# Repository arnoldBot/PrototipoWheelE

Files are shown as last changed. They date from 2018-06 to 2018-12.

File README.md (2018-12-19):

# PrototipoWheelE

Proyecto desarrollado por un grupo en la Universidad. El proyecto es un primer prototipo,
posteriormente se espera modificar el robot de 0 para hacer una nueva versión.

Es un diseño completo en el cuál se incluye:
  - Control Brazo Robótico
  - Servidor Web en Apache y página web
  - Control movimiento Rover
  - Diseño CAD del robot
  - Misceláneas varias

Especial mención a la parte del Servidor Web, en concreto a la implementación de la página web en Apache, ya que es totalmente funcional y extensible.

Se espera mejorar éste proyecto emplendo ROS y OpenCV.

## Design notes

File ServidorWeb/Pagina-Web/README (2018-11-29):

INSTRUCCIONES DE INSTALACIÓN Y PREPARACIÓN DE UN SERVIDOR WEB EMPLEANDO APACHE Y RASPBERRY PI

REQUISITOS PREVIOS
1-  Descargar de la página oficial de Raspberry Pi la distro de Jessie:
    https://www.raspberrypi.org/downloads/raspbian/

2-  Descargar la herramienta Rufus, para grabar imagenes iso en una SD:
    https://rufus.akeo.ie/?locale=es_ES
    (Posibilidad de emplear el comando "dd" en la terminal de Linux)

3-  Es NECESARIO emplear una tarjeta SD mayor a 8gb. (Formateada)
---------------------------------------------------------------------------------------------
INSTALACIÓN DE APACHE
4-  Grabamos la imagen de Jessie en nuestra SD y, posteriormente, introducimos la SD en la 
    Raspberry Pi y conectamos la alimentacion, una salida HDMI, un teclado y un ratón.
5-  Una vez se haya iniciado la Raspberry, abrimos la terminal y escribimos:
    "$ sudo raspi-config". Nos saltará otra interfaz, buscamos "Interfacing Options" y lo
    abrimos, ahí seleccionamos Camera, SSH y Serial.
    Vamos a atrás y le damos a "Advance Options" y seleccionamos "Expand Filesystem".
    Le damos a finish y la Raspberry Pi se reiniciará automaticamente.
6-  Posteriormente, de vuelta en el escritorio de Jessie, abrimos la terminal y escribimos:
    "$ sudo apt-get update".
7-  A continuación tecleamos: "$ sudo apt-get install apache2"
8-  Una vez instalado Apache en la Raspberry Pi, conviene comprobar si el servidor funciona.
    Para ello, necesitaremos un ordenador o dispositivo móvil, y conocer la ip de la Raspberry.
    Para comprobarlo, abrimos el navegador e introducimos en el browser la ip de la Raspberry
    y debería aparecer la página de Apache.

CONFIGURACIÓN DE APACHE
9-  Para configurarlo, en primer lugar debemos activar el cgi mediante: "$ sudo a2enmod cgi".
    Posteriormente, debemos configurar el directorio html, el cúal se encuentra en 
    /var/www/html/ para que pueda ejecutar scripts CGI. Para ello, debemos añadir las
    siguientes lineas de código al fichero apache2.config. (Éste fichero se encontrará dentro
    de /etc (creo), para abrirlo bastaría con: "$ sudo nano apache2.config".):

		~~~~~~~~~~~~~~~~~~~~~~~~~~~~~~~~~~~~~~~~~~~~~~~~~
		~	ScriptAlias  /cgi-bin/ /var/www/html/   ~
		~                                               ~
		~		<Directory /var/www/html/>      ~
		~    	    Options +ExecCGI                    ~
		~    	    AddHandler cgi-script .cgi .py      ~
		~		</Directory>                    ~
		~~~~~~~~~~~~~~~~~~~~~~~~~~~~~~~~~~~~~~~~~~~~~~~~~

   Una vez añadido, guardamos el archivo y reiniciamos la raspberry mediante: "$ sudo shutdown
   now".

ASIGNACIÓN DE PERMISOS
9-  Por defecto, el usuario apache estará dentro del grupo www-data, para tener los mismos
    permisos que apache, debemos añadir nuestro usuario, pi, a dicho grupo, es decir, www-data.
    Para ello, emplearemos el comando: "$ sudo adduser pi www-data".
10- A continuación, debemos hacer que el dueño del directorio /var/www/ pertenezca a al grupo
    www-data. Para ello, emplearemos: "$ sudo chown -R www-data:www-data /var/www".
    Ahora que hemos cambiado de dueño vamos a darle todo tipo de permimos al nuevo, para ello
    emplearemos el comando: "$sudo chmod -R g+rwX /var/www".
11- Por otro lado, debemos darle permisos de apertura, lectura y escritura a los archivos 
    (o carpetas) cgi que queremos que la página ejecute. Para ello emplearemos el comando:
    "$ sudo chmod 777 <nombrefichero.loquesea> (Hay que darselo a todos los archivos, es
    importante no olvidarlo).
12- Además, también es necesario darle permisos al grupo www-data para poder abrir los
    puertos. 
    Para ello, emplearemos: "$ sudo usermod -a -G dialout www-data".

TRANSFERENCIA DE DATOS CREADOS PARA LA WEB (CSS,HMTL,JS,ETC.)
13-  De vuelta a nuestro ordenador,debemos transferimos los datos creados en para la página web
    a la Raspberry, para ello emplearemos la herramienta "Filezilla". Para instalarla, abrimos
    la terminal y tecleamos: "$ sudo apt-get install filezilla".
14- Una vez dentro del programa, rellenamos los siguientes campos:
		host: <ip raspberry>
		username: <pi>
		password: <contraseña de la rasp> (Por defecto, pass=raspberry)
		port: <22>
15- Una vez nos hayas conectado a la Raspberry Pi mediante ssh empleando Filezilla, copiamos el
    contenido de la carpeta <Servidor_web> dentro de la ruta "/var/www/html/".
----------------------------------------------------------------------------------------
      DE ÉSTE MODO QUEDARÁ TOTALMENTE OPERATIVA LA RASPBERRY PI CON EL SERVIDOR PARA TRABAJAR
      CON ELLA.

----------------------------------------------------------------------------------------
ANEXO: ANTE POSIBLES PROBLEMAS CON PYTHON

Asegurar que el directorio de python es correcta en la primera lina de los scripts:
	para ello hacemos miramos si estan la libreria pySerial instalada correctamnte con:
	
		~$pip list 		// Si es python
			ó 
		~$pip3 list		// Si es python3
				
	si no esta la instalamos con:
	
		~$pip install <nombre del paquete> (la que necesitamos es pySerial) // Si es python
			ó
		~$pip3 install <nombre del paquete>		// Si es python3

	segun en donde este instalado (python3 o python) hacemos lo siguiente:
	
		~$which python
			ó 
		~$which python3
		
	nos aparecera el directorio del interprete de python
	y dentro de los scripts CGI de python ponemos en la primera linea:
	
		#!<RUTA DEL INTERPRETE>

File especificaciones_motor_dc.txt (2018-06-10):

especificaciones motor dc

 1. tensión : CC 3V - 6v
 2. corriente : 100 mA- 120mA
 3. tasa de reducción : 48 : 1
 4. rpm (con neumáticos ) : 100-240
 5. diámetro de los neumáticos : 65mm
 6. la velocidad del vehículo (m / minuto ) : 20-48
 7. peso del motor ( g): 29 / cada una
 8. tamaño del motor : 70mm x 22mm x 18mm
9. Ruido: \u003c65db

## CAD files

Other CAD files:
DiseñoCAD/Brazo Robotico/Engranaje_motor.CATPart
DiseñoCAD/Brazo Robotico/Engranaje_no_motor.CATPart
DiseñoCAD/Brazo Robotico/Part1.CATPart
DiseñoCAD/Brazo Robotico/Part2.CATPart
DiseñoCAD/Brazo Robotico/Part3.CATPart
DiseñoCAD/Brazo Robotico/Part4.CATPart
DiseñoCAD/Brazo Robotico/Part5.CATPart
DiseñoCAD/Brazo Robotico/Part6.CATPart
DiseñoCAD/Brazo Robotico/Part7.CATPart
DiseñoCAD/Brazo Robotico/Part8.CATPart
DiseñoCAD/Brazo Robotico/Product1.CATProduct
DiseñoCAD/Brazo Robotico/ServoMount.CATPart
DiseñoCAD/Chasis/28BYJ-48 stepper motor.CATPart
DiseñoCAD/Chasis/Baterias/Bateria.CATProduct
DiseñoCAD/Chasis/Part.CATPart
DiseñoCAD/Chasis/Part1.CATPart
DiseñoCAD/Chasis/Part10.CATPart
DiseñoCAD/Chasis/Part11.CATPart
DiseñoCAD/Chasis/Part22.CATPart
DiseñoCAD/Chasis/Part3.CATPart
DiseñoCAD/Chasis/Part33.CATPart
DiseñoCAD/Chasis/Part44.CATPart
DiseñoCAD/Chasis/Part5.CATPart
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

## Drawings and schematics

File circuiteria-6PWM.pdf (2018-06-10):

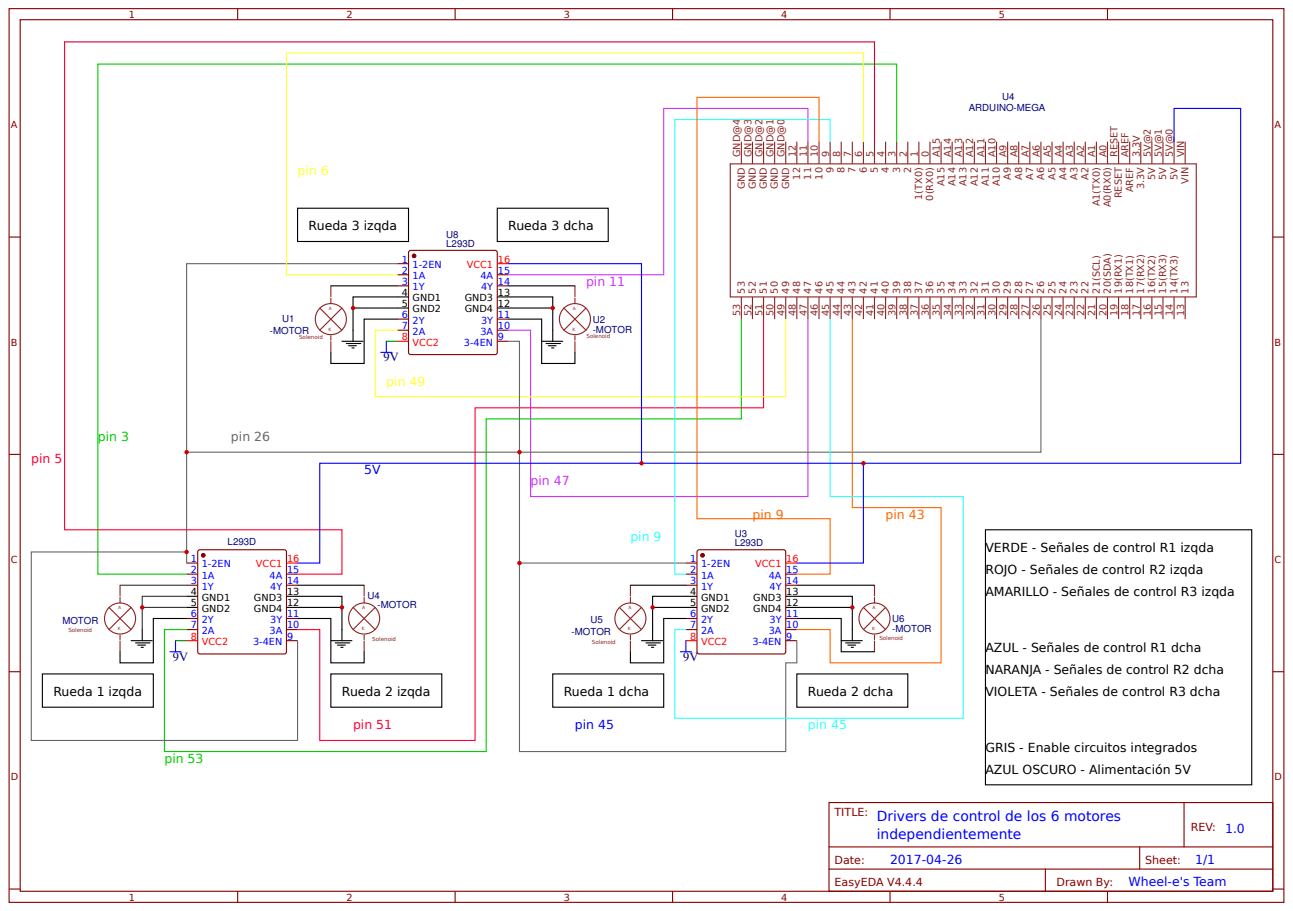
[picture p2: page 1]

GND GND@0 GND GND@1 GND GND@2 GND GND@3 53 53 52 52 51 51 50 50 49 49

VERDE - Señales de control R1 izqda
ROJO - Señales de control R2 izqda
AMARILLO - Señales de control R3 izqda

AZUL - Señales de control R1 dcha
NARANJA - Señales de control R2 dcha
VIOLETA - Señales de control R3 dcha

GRIS - Enable circuitos integrados
AZUL OSCURO - Alimentación 5V

TITLE: Drivers de control de los 6 motores

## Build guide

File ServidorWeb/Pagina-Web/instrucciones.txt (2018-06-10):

1.-	Instalar apache:

	~$sudo apt-get install apache2
	
2.-	Activar cgi:

	~$sudo a2enmod cgi

3.-	Configurar directorio html contenido en /var/www/html/ para que pueda ejecutar scripts CGI con el siguente codigo en 		el fichero apache2.config:

	~$sudo nano apache2.config
	
	// Dentro de fichero colocamos esto //
		ScriptAlias  /cgi-bin/ /var/www/html/

		<Directory /var/www/html/>
    	    Options +ExecCGI
    	    AddHandler cgi-script .cgi .py
		</Directory>

4.-	Por defecto el nombre de usuario de apache es www-data, por lo que tenemos que darle los permisos a www-data y a tu 	usuario para poder editar todo lo que hay dentro del directorio www: 

		~$sudo adduser pi www-data
		~$sudo chown -R www-data:www-data /var/www
		~$sudo chmod -R g+rwX /var/www

5.-	Daremos los permisos a www-data a todos los archivos cgi o .py que quieras que la pagina ejecute:

		~$sudo chmod 755 nombrefichero.py

6.-	Daremos permisos a www-data para abrir y escribir archivos .txt

		~$sudo chmod 755 nombrefichero.txt

7.-	Daremos permisos a www-data para abrir el puerto serie:

		~$sudo usermod -a -G dialout www-data

8.-	Asegurar que el directorio de python es correcta en la primera lina de los scripts:
	para ello hacemos miramos si estan la libreria pySerial instalada correctamnte con:
	
		~$pip list 		// Si es python
			ó 
		~$pip3 list		// Si es python3
				
	si no esta la instalamos con:
	
		~$pip install <nombre del paquete> (la que necesitamos es pySerial) // Si es python
			ó
		~$pip3 install <nombre del paquete>		// Si es python3

	segun en donde este instalado (python3 o python) hacemos lo siguiente:
	
		~$which python
			ó 
		~$which python3
		
	nos aparecera el directorio del interprete de python
	y dentro de los scripts CGI de python ponemos en la primera linea:
	
		#!<RUTA DEL INTERPRETE>

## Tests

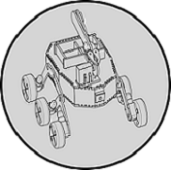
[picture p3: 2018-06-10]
ServidorWeb/Pagina-Web/images/prueba.png

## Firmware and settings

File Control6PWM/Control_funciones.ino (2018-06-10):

//es necesario implementar toda la botonera, configurar el estado de subida de escalones y además, el de movimiento normal. Por otro lado hay que nombrar a cada variable
//de tal modo (y generar una tabla de variables) que sea sencillo identificar cada una para los script de Python.
//w - recto
//q - avance hacia la izqda
//a - rotacion sobre si mismo sent antihorario
//z - retroceso haci la izquierda 
//x - marcha atras
//c - retroceso hacia la dcha
//d - rotacion sobre si mismo sent horario
//e - avance hacia la dcha
//m - turbo(max.par)
//n - modo normal
//s - stop

//DECLARACIÓN DE VARIABLES
#define Enable_pH 26 //Pin 1(Habilitación de cada puente H)

#define PWM_R1_IZQ 3 //PWM Rueda 1 Izquierda
#define PWM_R2_IZQ 5 //PWM Rueda 2 Izquierda
#define PWM_R3_IZQ 6 //PWM Rueda 3 Izquierda
#define PWM_R1_DER 9 //PWM Rueda 1 Derecha
#define PWM_R2_DER 10 //PWM Rueda 2 Derecha
#define PWM_R3_DER 11 //PWM Rueda 3 Derecha

#define DIG_R1_IZQ 53 //senal Digital Rueda 1 Izquierda
#define DIG_R2_IZQ 51 //senal Digital Rueda 2 Izquierda
#define DIG_R3_IZQ 49 //senal Digital Rueda 3 Izquierda
#define DIG_R1_DER 45 //senal Digital Rueda 1 Derecha
#define DIG_R2_DER 43 //senal Digital Rueda 2 Derecha
#define DIG_R3_DER 47 //senal Digital Rueda 3 Derecha

char ch; //en esta variable se almacenará la direccion que le pasemos por puerto serie.

//con estas variables guardamos la direccion en la que se estaba moviendo el coche para no estar enviando constantemente una tecla de direccion
int delante=0; //tecla w
int atras=0; //tecla x
int av_dcha=0; //tecla e
int av_izqda=0; //tecla q
int antihorario=0; //tecla a
int horario=0; //tecla d
int ret_izqda=0; //tecla z
int ret_dcha=0; //tecla c

int max_par=0; //tecla m

//----------------------------------------------------------------------------------------------------

void setup() {
  // put your setup code here, to run once:

  Serial.begin(9600); // iniciamos el puerto serie
  
  //Declaramos los pines como salidas de Arduino.
  pinMode(PWM_R1_IZQ,OUTPUT); 
  pinMode(PWM_R2_IZQ,OUTPUT);  
  pinMode(PWM_R3_IZQ,OUTPUT);
  pinMode(PWM_R1_DER,OUTPUT);
  pinMode(PWM_R2_DER,OUTPUT);
  pinMode(PWM_R3_DER,OUTPUT);

  pinMode(DIG_R1_IZQ,OUTPUT); 
  pinMode(DIG_R2_IZQ,OUTPUT);  
  pinMode(DIG_R3_IZQ,OUTPUT);
  pinMode(DIG_R1_DER,OUTPUT);
  pinMode(DIG_R2_DER,OUTPUT);
  pinMode(DIG_R3_DER,OUTPUT);  
  
  pinMode(Enable_pH, OUTPUT);//senal de enable de los puentes H

}

//------------------------------------------------------------------------------------------------------

void loop() {
  // put your main code here, to run repeatedly:
  
  //Vamos a crear 6 posibilidades de movimiento: al pulsar 'W' avanzará hacia delante, al pulsar 'S' retrocederá, al pulsar la
  //tecla 'A' girará sobre si mismo en sentido antihorario, al pulsar 'D' girará sobre sí mismo en sentido horario, al pulsar
  //la tecla 'Q', avanzará hacia la izquierda y al pulsar 'E' avanzará hacia la derecha.
  
if(Serial.available()) //si el puerto serie esta libre
{
    ch=Serial.read(); //almacenamos el valor que se lea del puerto serie.

        if(ch=='w' && not(( delante==1 && ch!='w'))) // si pulsamos hacia delante o se estaba moviendo hacia delante
        {
          delante=1; //tecla w
          atras=0; //tecla x
          av_dcha=0; //tecla e
          av_izqda=0; //tecla q
          antihorario=0; //tecla a
          horario=0; //tecla d
          ret_izqda=0; //tecla z
          ret_dcha=0; //tecla c          
          max_par=0; //tecla m        
          salida_motores (HIGH, 200,LOW, 200,LOW, 200,LOW, 200,LOW, 200,LOW, 200,LOW);   
        }
    
        else if (ch== 'x'  && not(( atras==1 && ch!='x'))) // si pulsamos 'X' hacia atras o se estaba moviendo hacia atras
        { 
          delante=0; //tecla w
          atras=1; //tecla x
          av_dcha=0; //tecla e
          av_izqda=0; //tecla q
          antihorario=0; //tecla a
          horario=0; //tecla d
          ret_izqda=0; //tecla z
          ret_dcha=0; //tecla c          
          max_par=0; //tecla m          
          salida_motores (HIGH ,(255-200),HIGH ,(255-200),HIGH ,(255-200),HIGH ,(255-200),HIGH ,(255-200),HIGH ,(255-200),HIGH);
        }
        
      else if( ch =='d' && not(( horario==1 && ch!='d'))) // si pulsamos 'D', girará sobre sí mismo en sentido horario.
      { 
          delante=0; //tecla w
          atras=0; //tecla x
          av_dcha=0; //tecla e
          av_izqda=0; //tecla q
          antihorario=0; //tecla a
          horario=1; //tecla d
          ret_izqda=0; //tecla z
          ret_dcha=0; //tecla c          
          max_par=0; //tecla m
          salida_motores (HIGH ,128,LOW ,128,LOW, 128,LOW ,(255-128),HIGH ,(255-128),HIGH ,(255-128),HIGH);        
      }
    
      else if(ch =='a' && not(( antihorario==1 && ch!='a')))   // si pulsamos 'A', girará sobre sí mismo en sentido antihorario.
      {
          delante=0; //tecla w
          atras=0; //tecla x
          av_dcha=0; //tecla e
          av_izqda=0; //tecla q
          antihorario=1; //tecla a
          horario=0; //tecla d
          ret_izqda=0; //tecla z
          ret_dcha=0; //tecla c          
          max_par=0; //tecla m
          salida_motores (HIGH ,(255-200),HIGH ,(255-200), HIGH,(255-200), HIGH, 200,LOW ,200,LOW, 200,LOW);        
      }    
     
      else if(ch =='q' && not(( av_izqda==1 && ch!='q'))) //Al pulsar 'Q' avanzará hacia la izquierda.
      { 
          delante=0; //tecla w
          atras=0; //tecla x
          av_dcha=0; //tecla e
          av_izqda=1; //tecla q
          antihorario=0; //tecla a
          horario=0; //tecla d
          ret_izqda=0; //tecla z
          ret_dcha=0; //tecla c          
          max_par=0; //tecla m
          salida_motores (HIGH ,128,LOW ,128,LOW, 128,LOW ,255,LOW ,255,LOW ,255,LOW);
      }

      else if(ch =='e' && not(( av_dcha==1 && ch!='e')))  //Al pulsar 'E', avanzará hacia la derecha
      {   
          delante=0; //tecla w
          atras=0; //tecla x
          av_dcha=1; //tecla e
          av_izqda=0; //tecla q
          antihorario=0; //tecla a
          horario=0; //tecla d
          ret_izqda=0; //tecla z
          ret_dcha=0; //tecla c
          max_par=0; //tecla m
          salida_motores (HIGH ,255,LOW ,255,LOW, 255,LOW ,128,LOW ,128,LOW ,128,LOW);
      }
      
      else if(ch =='z' && not(( ret_izqda==1 && ch!='z')))  //Al pulsar 'Z', retrocederá hacia la izquierda
      {   
          delante=0; //tecla w
          atras=0; //tecla x
          av_dcha=0; //tecla e
          av_izqda=0; //tecla q
          antihorario=0; //tecla a
          horario=0; //tecla d
          ret_izqda=1; //tecla z
          ret_dcha=0; //tecla c 
          max_par=0; //tecla m
          salida_motores (HIGH ,(255-128),HIGH ,(255-128),HIGH, (255-128),HIGH ,(255-255),HIGH ,(255-255),HIGH ,(255-255),HIGH);
      }
      
      else if(ch =='c' && not(( ret_dcha==1 && ch!='c')))  //Al pulsar 'C', retrocederá hacia la derecha
      {   
          delante=0; //tecla w
          atras=0; //tecla x
          av_dcha=0; //tecla e
          av_izqda=0; //tecla q
          antihorario=0; //tecla a
          horario=0; //tecla d
          ret_izqda=0; //tecla z
          ret_dcha=1; //tecla c          
          max_par=0; //tecla m
          salida_motores (HIGH ,(255-255),HIGH ,(255-255),HIGH,(255-255),HIGH ,(255-128),HIGH ,(255-128),HIGH ,(255-128),HIGH);
      }

      else if(ch =='m' && not(( max_par==1 && ch!='m')))  //Al pulsar 'M', intentaremos obtener el maximo par de las ruedas
      {   
          delante=0; //tecla w
          atras=0; //tecla x
          av_dcha=0; //tecla e
          av_izqda=0; //tecla q
          antihorario=0; //tecla a
          horario=0; //tecla d
          ret_izqda=0; //tecla z
          ret_dcha=0; //tecla c          
          max_par=1; //tecla m
          salida_motores (HIGH , 65, LOW , 120 ,LOW, 230 , LOW,65 ,LOW, 120 ,LOW, 230 ,LOW);
      }

       else if(ch =='p') // si pulsamos 'P' se parará el vehículo.
      { 
          salida_motores (LOW ,255,HIGH ,255,HIGH ,255,HIGH ,255,HIGH ,255,HIGH ,255,HIGH);       
      }
  }
}


//----------------------------------------------------------------------------------------------------------------------
//FUNCION PARA OPTIMIZAR EL CÓDIGO DE SALIDA DEL MOTOR

//Esta función está basada en la tabla de verdad del motor y controlandolo mediante una señal PWM y otra lógica.
//http://www.iescamp.es/miarduino/2016/02/21/2-motores-de-cc-velocidad-y-cambio-de-sentido/ en este enlace aparece la tabla de verdad y el porqué de las cosas.
//ADEMÁS, LA TABLA DE VERDAD SE ENCONTRARÁ EN EL .TXT DE GIT DÓNDE SE ENCUENTRAS LAS VARIABLES DEL SISTEMA DE CONTROL DE MOVIMIENTO.

void salida_motores (char senal_enable,char vel_R1_izqda,char senal_R1_izqda,char vel_R2_izqda,char senal_R2_izqda,char vel_R3_izqda,char senal_R3_izqda,char vel_R1_dcha,char senal_R1_dcha,char vel_R2_dcha,char senal_R2_dcha,char vel_R3_dcha,char senal_R3_dcha)
{
          digitalWrite(Enable_pH, senal_enable);

          analogWrite(PWM_R1_IZQ, vel_R1_izqda);   
          digitalWrite(DIG_R1_IZQ, senal_R1_izqda);  
          
          analogWrite(PWM_R2_IZQ, vel_R2_izqda);
          digitalWrite(DIG_R2_IZQ, senal_R2_izqda);

          analogWrite(PWM_R3_IZQ, vel_R3_izqda);
          digitalWrite(DIG_R3_IZQ, senal_R3_izqda);

          analogWrite(PWM_R1_DER, vel_R1_dcha);
          digitalWrite(DIG_R1_DER, senal_R1_dcha);

          analogWrite(PWM_R2_DER, vel_R2_dcha);
          digitalWrite(DIG_R2_DER, senal_R2_dcha);

          analogWrite(PWM_R3_DER, vel_R3_dcha);
          digitalWrite(DIG_R3_DER, senal_R3_dcha); 
}

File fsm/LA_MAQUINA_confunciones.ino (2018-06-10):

#include <Servo.h>
//es necesario implementar toda la botonera, configurar el estado de subida de escalones y además, el de movimiento normal. Por otro lado hay que nombrar a cada variable
//de tal modo (y generar una tabla de variables) que sea sencillo identificar cada una para los script de Python.
//w - recto
//q - avance hacia la izqda
//a - rotacion sobre si mismo sent antihorario
//z - retroceso haci la izquierda
//x - marcha atras
//c - retroceso hacia la dcha
//d - rotacion sobre si mismo sent horario
//e - avance hacia la dcha
//m - turbo(max.par)
//n - modo normal
//p - stop
//b - brazo

//LISTA DE ESTADOS
//0 - estado inicial con todos los  motores parados
// 1 - el coche se está moviendo hacia delante
// 2 - el coche se mueve hacia atrás
// 3 - el coche gira sobre si mismo en sentido horario
//4 - el coche gira sobre si mismo en sentido antihorario
//5 - el coche avanza hacia la izquierda
//6 - el coche avanza hacia la derecha
//7-el coche retrocede hacia la izquierda
//8 - el coche retrocede hacia la derecha
//9 - paramos el movimiento del coche
// 10 - pasamos al movimiento del brazo y detenemos el movimiento del coche


//DECLARACIÓN DE VARIABLES
#define Enable_pH 26 //Pin 1(Habilitación de cada puente H)

#define PWM_R1_IZQ 3 //PWM Rueda 1 Izquierda
#define PWM_R2_IZQ 5 //PWM Rueda 2 Izquierda
#define PWM_R3_IZQ 6 //PWM Rueda 3 Izquierda
#define PWM_R1_DER 9 //PWM Rueda 1 Derecha
#define PWM_R2_DER 10 //PWM Rueda 2 Derecha
#define PWM_R3_DER 11 //PWM Rueda 3 Derecha

#define DIG_R1_IZQ 53 //senal Digital Rueda 1 Izquierda
#define DIG_R2_IZQ 51 //senal Digital Rueda 2 Izquierda
#define DIG_R3_IZQ 49 //senal Digital Rueda 3 Izquierda
#define DIG_R1_DER 45 //senal Digital Rueda 1 Derecha
#define DIG_R2_DER 43 //senal Digital Rueda 2 Derecha
#define DIG_R3_DER 47 //senal Digital Rueda 3 Derecha

String ch; //en esta variable se almacenará la direccion que le pasemos por puerto serie.

//con estas variables guardamos la direccion en la que se estaba moviendo el coche para no estar enviando constantemente una tecla de direccion
char delante = 0; //tecla w
char atras = 0; //tecla x
char av_dcha = 0; //tecla e
char av_izqda = 0; //tecla q
char antihorario = 0; //tecla a
char horario = 0; //tecla d
char ret_izqda = 0; //tecla z
char ret_dcha = 0; //tecla c

char max_par = 0; //tecla m
char estado = 0;//declaramos la variable para la máquina de estados
char inicio = 0;
char deltax = 0; //distancia del objeto al centro de la pantalla en horizontal
char deltay = 0; //distancia del objeto al centro de la pantalla en vertical

char xerror = 0;
char yerror = 0;
//----------------------------------------------------------------------------------------------------

//DECLARACION DE VARIABLES DEL BRAZO
// La secuencia de pulsos que hay que dar a cada bobina del paso a paso para que gire el eje.
int Paso[8][4] =
{ {1, 0, 0, 0},
  {1, 1, 0, 0},
  {0, 1, 0, 0},
  {0, 1, 1, 0},
  {0, 0, 1, 0},
  {0, 0, 1, 1},
  {0, 0, 0, 1},
  {1, 0, 0, 1}
};

// Definimos los pines del paso a paso. Hay que cambiarlo en funcion de los disponibles del Ard.Mega
#define IN1  32
#define IN2  36
#define IN3  34
#define IN4  38

int steps_left = 4095; // Variable que contiene el numero de pasos quedan por dar.
boolean Direction = true; // Variable que indica la direccion, es decir, si la secuencia de pulsos va en un sentido o el otro.
int Steps = 0; // Define el paso actual de la secuencia.
int currentAngle = 0; // Indica el angulo actual del motor.
int angulo = 0; // Variable que contiene el angulo al que se quiere llegar.

Servo hombroServo;
Servo codoServo;
Servo efectorfinal;
Servo baseServo;

int i = 0;
int estadobrazo = 1;
int color = -1;  // rojo  = 0
// verde = 1
// Azul  = 2
// Amarillo = 3
float A;
float L0 = 55;  // No es necesario porque el sistema de referencia se pone en la primera articulación para facilitar calculos.
float L2 = 135;
float L3 = 150; // Aproximadamente para que el objeto se encuentra dentro del efector
int x, y, z;
int coordenada[10];
float angulo0 = 0;
float angulo2 = 90;
float angulo3 = 60;
float anguloEfector = 10;
int bufferChar;
int pos_servo_base;
int pos_servo_hombro;
int pos_servo_codo;


//----------------------------------------------------------------------------------------------------
void setup() {
  // put your setup code here, to run once:

  Serial.begin(9600); // iniciamos el puerto serie

  //Declaramos los pines como salidas de Arduino.
  pinMode(PWM_R1_IZQ, OUTPUT);
  pinMode(PWM_R2_IZQ, OUTPUT);
  pinMode(PWM_R3_IZQ, OUTPUT);
  pinMode(PWM_R1_DER, OUTPUT);
  pinMode(PWM_R2_DER, OUTPUT);
  pinMode(PWM_R3_DER, OUTPUT);

  pinMode(DIG_R1_IZQ, OUTPUT);
  pinMode(DIG_R2_IZQ, OUTPUT);
  pinMode(DIG_R3_IZQ, OUTPUT);
  pinMode(DIG_R1_DER, OUTPUT);
  pinMode(DIG_R2_DER, OUTPUT);
  pinMode(DIG_R3_DER, OUTPUT);

  pinMode(Enable_pH, OUTPUT);//senal de enable de los puentes H

  //declaramos los pines del brazo
  // Definimos el modo de los pines.
  //  pinMode(IN1, OUTPUT);
  //  pinMode(IN2, OUTPUT);
  //  pinMode(IN3, OUTPUT);
  //  pinMode(IN4, OUTPUT);
  //
  delay(2000);
  codoServo.attach(11);              //Arduino pone por defecto: para cero grados 544 y para 180 2400.
  delay(2000);
  efectorfinal.attach(10);  //Arduino pone por defecto: para cero grados 544 y para 180 2400.
  delay(2000);
  hombroServo.attach(6);            //Arduino pone por defecto: para cero grados 544 y para 180 2400.
  delay(2000);
  baseServo.attach(5);            //Arduino pone por defecto: para cero grados 544 y para 180 2400.

  hombroServo.write(0);
  delay(500);
  hombroServo.write(90);
  delay(500);
  codoServo.write(0);
  delay(500);
  codoServo.write(90);
  delay(500);
  efectorfinal.write(10);
  delay(500);
  efectorfinal.write(10);
}


//------------------------------------------------------------------------------------------------------
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
